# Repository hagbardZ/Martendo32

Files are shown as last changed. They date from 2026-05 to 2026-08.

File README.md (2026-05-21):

2026-04-28 11_06_20-_ Martendo32_Housingb_IPS - FreeCAD 1 1 1_C

assets/65467d34-9345-4316-92dd-8e191f508759" />
Kicad files for Martendo32.
An ESP32-P4 based Retro Game console

Martendo32Top

Martendo32BOT

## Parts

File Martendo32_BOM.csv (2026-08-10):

ID | Bezeichner | Footprint | Stückzahl | Bezeichnung | Anbieter und Referenz
1 | C1, C2, C3, C5, C7, C8 | 0603 | 6 | 10uF
2 | C4, C6, C9, C10, C11 | 0603 | 5 | 100nF
3 | C12 | 0805 | 1 | 10uF
4 | CN2 | CONN-SMD_2P-P1.25_D125F2W1-2W2P43 | 1 | ZX-MX1.25-2PWT
5 | CONBAT1, CONBAT2 | PinHeader_1x01_P2.54mm_Vertical | 2 | Conn_01x01
6 | CONBAT3, CONBAT4 | TestPoint_Pad_3.0x3.0mm | 2 | Conn_01x01
7 | D1 | SOD-123_L2.7-W1.6-LS3.7-RDaaa | 1 | 1N5819W
8 | D2 | SOD-123FL_L2.7-W1.8-LS3.8-RD | 1 | DSK24
9 | J1 | AUDIO-SMD_HOOYA_PJ-242a | 1 | AudioJack4_SwitchTR1
10 | J2 | PinSocket_1x03_P2.54mm_Vertical | 1 | Conn_01x03
11 | J3 | 687118183722 | 1 | Conn_01x18_Socket
12 | J4 | AMPHENOL_GSB1C41110SSHR | 1 | USB-C
13 | key_a1, key_down1, key_down2, key_left1, key_left2, key_right1, key_right2, key_select1, key_start1, key_up1, key_up2 | 430451031836 | 11 | TS-1187A-B-A-B
14 | key_a2 | DTSM-6 | 1 | TS-1187A-B-A-B
15 | L1 | IND-SMD_L2.5-W2.0_MHCH252012A | 1 | 4.7uH
16 | LCD1 | ILI9341-2.8a | 1 | Conn_01x18
17 | LED1 | LED0603-RD_GREEN | 1 | ~
18 | LED2 | LED0603-RD_RED | 1 | ~
19 | Q1 | SOT-23-3_L2.9-W1.6-P1.90-LS2.8-BRaaa | 1 | NPN
20 | Q2 | SOT-23-3_L2.9-W1.6-P1.90-LS2.8-BR | 1 | AO3401A
21 | R1, R13 | 0603 | 2 | 10K
22 | R2, R22, R23 | 0603 | 3 | 100K
23 | R3 | 0603 | 1 | 2K
24 | R4, R6, R7 | 0603 | 3 | 5K1
25 | R5, R14, R25 | 0603 | 3 | 1K
26 | R8 | 0603 | 1 | 240R
27 | R9, R10, R11, R12 | 0603 | 4 | 10R
28 | R15, R16, R17, R18, R19 | 0603 | 5 | 10kΩ
29 | R20 | 0603 | 1 | 220K
30 | R21 | 0603 | 1 | 680K
31 | R24 | 0603 | 1 | 10K
32 | R26 | R_0603_1608Metric_Pad0.98x0.95mm_HandSolder | 1 | 10K
33 | R111 | 0603 | 1 | 0R
34 | REF** | BATT_CONN_SMT_292173 | 1 | BATT_CONN_SMT_292173
35 | RP1, RP2 | Adafruit_2765 | 2 | Adafruit_2765
36 | SD1 | TF-SMD_TF-01A | 1 | ~
37 | SPK1, SPK11 | TestPoint_Pad_D2.5mm | 2 | Conn_01x01
38 | SW1 | SW-SMD_MSK12C02-HB | 1 | SK-3296S-01-L3
39 | SW_BOOT1, SW_RST1 | SW-SMD_L3.9-W3.0-P4.45 | 2 | 3*4 龟仔/微动/轻触开关
40 | TP1, TP2, TP3, TP4, TP5, TP6, TP7, TP8, TP9, TP10, TP11, TP12, TP13, TP14, TP15, TP16, TP17, TP18, TP19, TP20, TP21, TP22, TP23 | TestPoint_Pad_D1.0mm | 23 | TestPoint
41 | U1 | COMM-SMD_L25.0-W20.0-P1.00_WT0132P4-A1 | 1 | ~
42 | U3 | ESOP-8_L4.9-W3.9-P1.27-LS6.0-BL-EP | 1 | TP4056
43 | U4 | ESOP-8_L4.9-W3.9-P1.27-LS6.0-BL-EP | 1 | NS4168
44 | U5 | SOT-23-5_L3.0-W1.7-P0.95-LS2.8-BR | 1 | TPS61040DBV
45 | U6 | SOT-23-5_L2.9-W1.6-P0.95-LS2.8-BR | 1 | AP2112K-3.3
46 | VR1 | RK10J11E002Y | 1 | RK10J11E002Y
47 | X22, X23 |  | 2

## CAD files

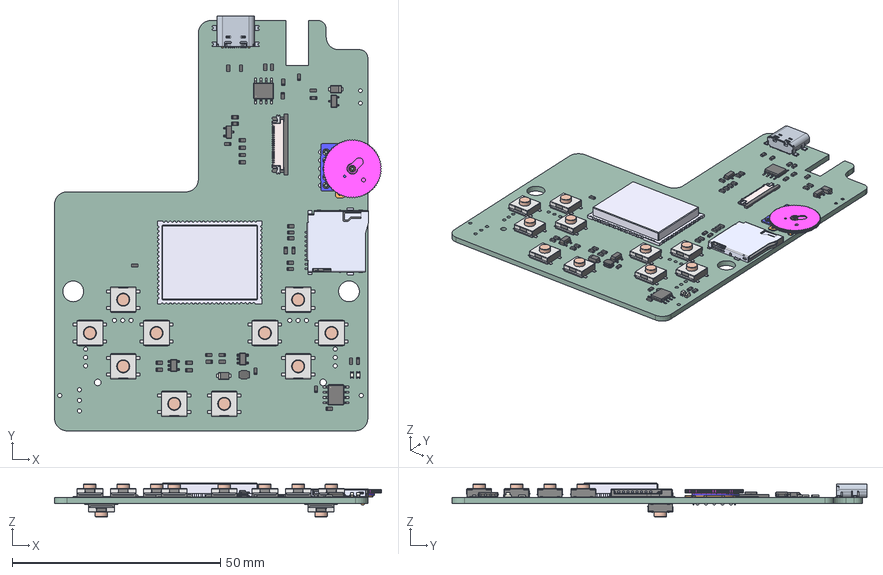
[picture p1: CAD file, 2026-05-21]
Martendo32_PCBA_V2.2.step
78.5 x 99.6 x 8.08 mm
R_0603_1608Metric x 37
base x 12
top cover x 12
6081697a-9268-11ed-8af4-a0cec80452fd_part x 2
60816e3e-9268-11ed-8af4-a0cec80452fd_part x 2
6081710e-9268-11ed-8af4-a0cec80452fd_part x 2
6081737a-9268-11ed-8af4-a0cec80452fd_part x 2
SOT-23-3 x 2
68x118183x22
68X1XX183X22_Pin_Bottom x 18
68x118183x22_Actuator
68X1XX183X22_Solder_Pad
68X1xx183x22_Solder_Pad2
TF-01A_TF-01A
HTSOP-8-1EP_3.9x4.9mm_P1.27mm_EP2.4x3.2mm x 2
_16P_7_35_3D_
SOT-23-5 x 2
LED_0603_1608Metric_Castellated x 2
RK10J1_E
L_Wurth_WE-LQSH-2010
L_Wurth_WE-LQSH-2512
Martendo32_PCB

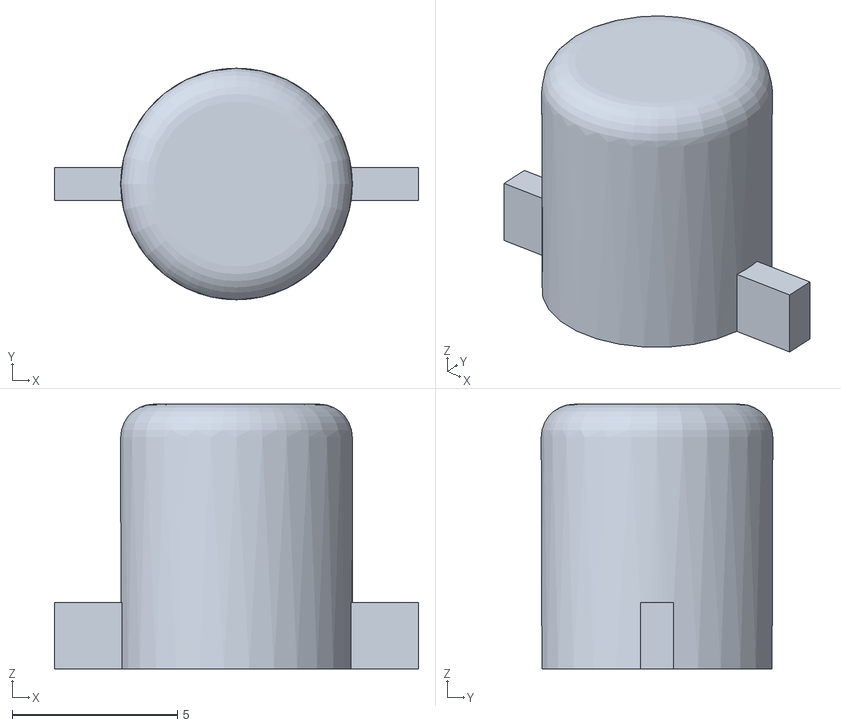
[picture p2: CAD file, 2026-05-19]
Martendo32_H-Button.stl
11.0 x 7.00 x 8.00

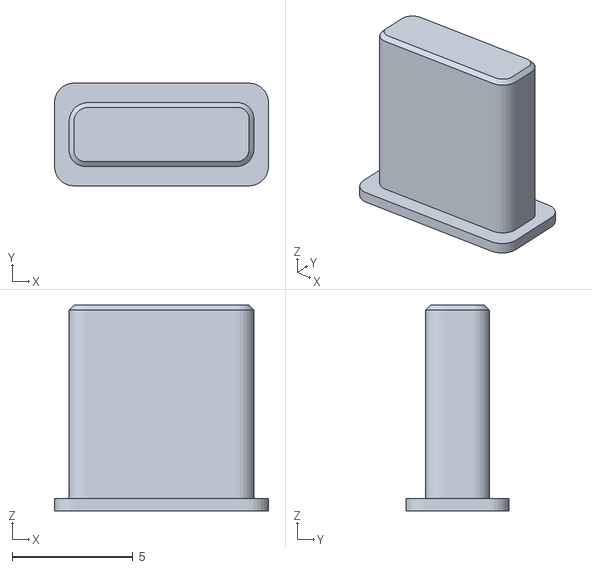
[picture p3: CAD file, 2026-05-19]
Martendo32_H-ButtonUnten.stl
8.85 x 4.25 x 8.50

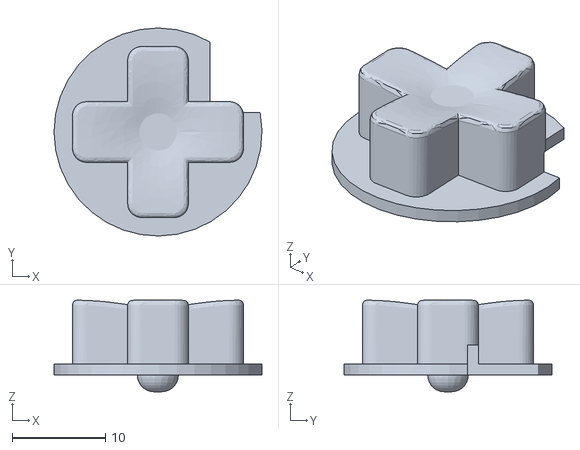
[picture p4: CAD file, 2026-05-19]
Martendo32_H_Steuerkreuz.stl
22.2 x 22.2 x 9.80

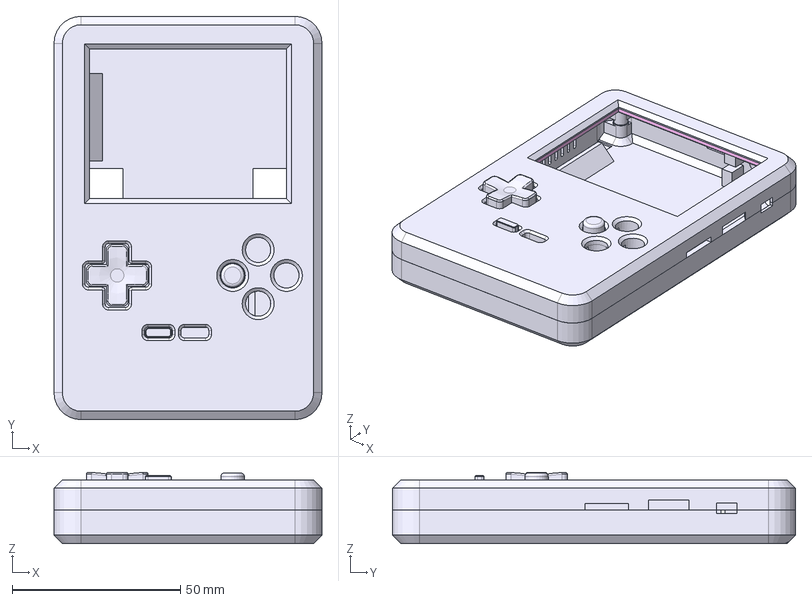
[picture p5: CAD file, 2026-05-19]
Martendo32_H.step
79.8 x 120.0 x 21.2 mm
Steuerkreuz002
Button001
ButtonUnten
GUT002_mitVertiefungen
IPS-FRAME_extrude
GOT002_M2Inserts
Insert_M2 v2
Insert_M2 v001
Insert_M2 v002
Insert_M2 v003
Insert_M2 v004
Insert_M2 v005

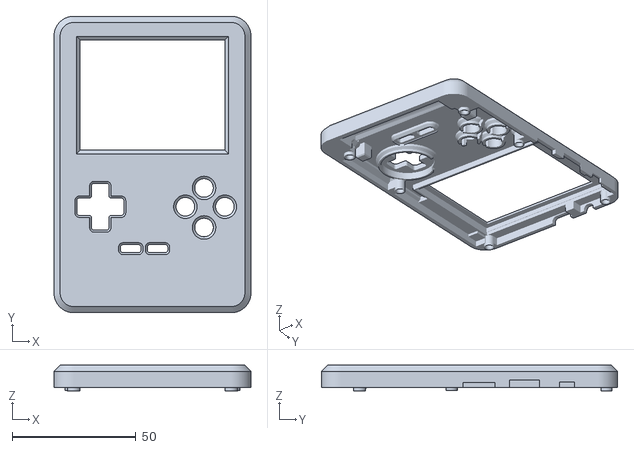
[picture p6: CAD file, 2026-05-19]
Martendo32_H_GOT.stl
79.8 x 120.0 x 10.4

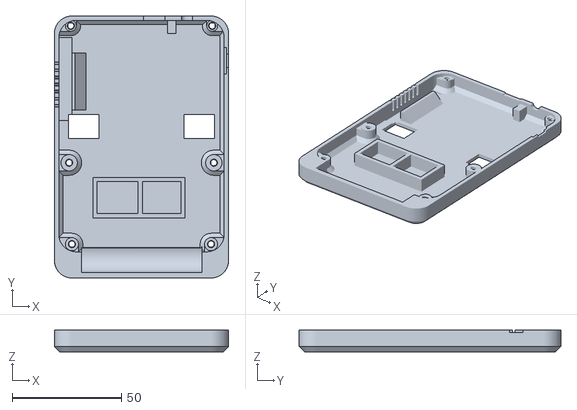
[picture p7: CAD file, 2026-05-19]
Martendo32_H_GUT.stl
79.8 x 120.0 x 10.0

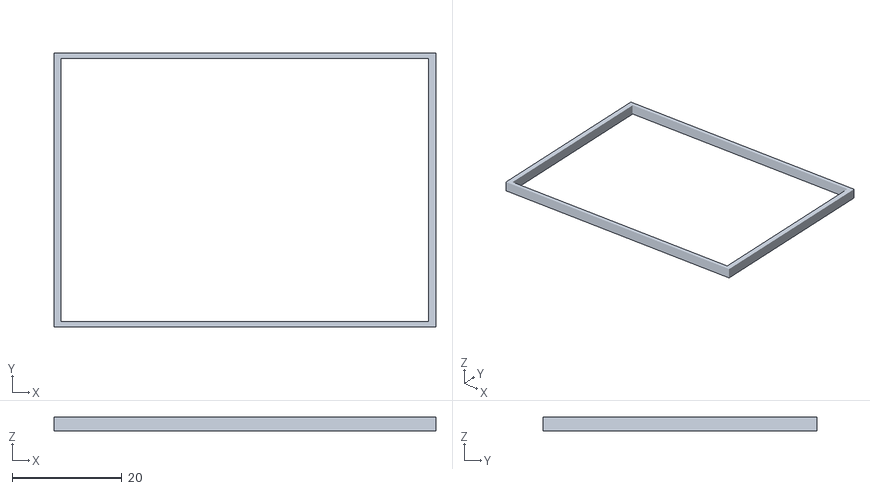
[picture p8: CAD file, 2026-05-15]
Martendo32_H_IPS-FRAME.stl
69.7 x 49.9 x 2.50

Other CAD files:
Martendo32_Housingh-IPS.FCStd

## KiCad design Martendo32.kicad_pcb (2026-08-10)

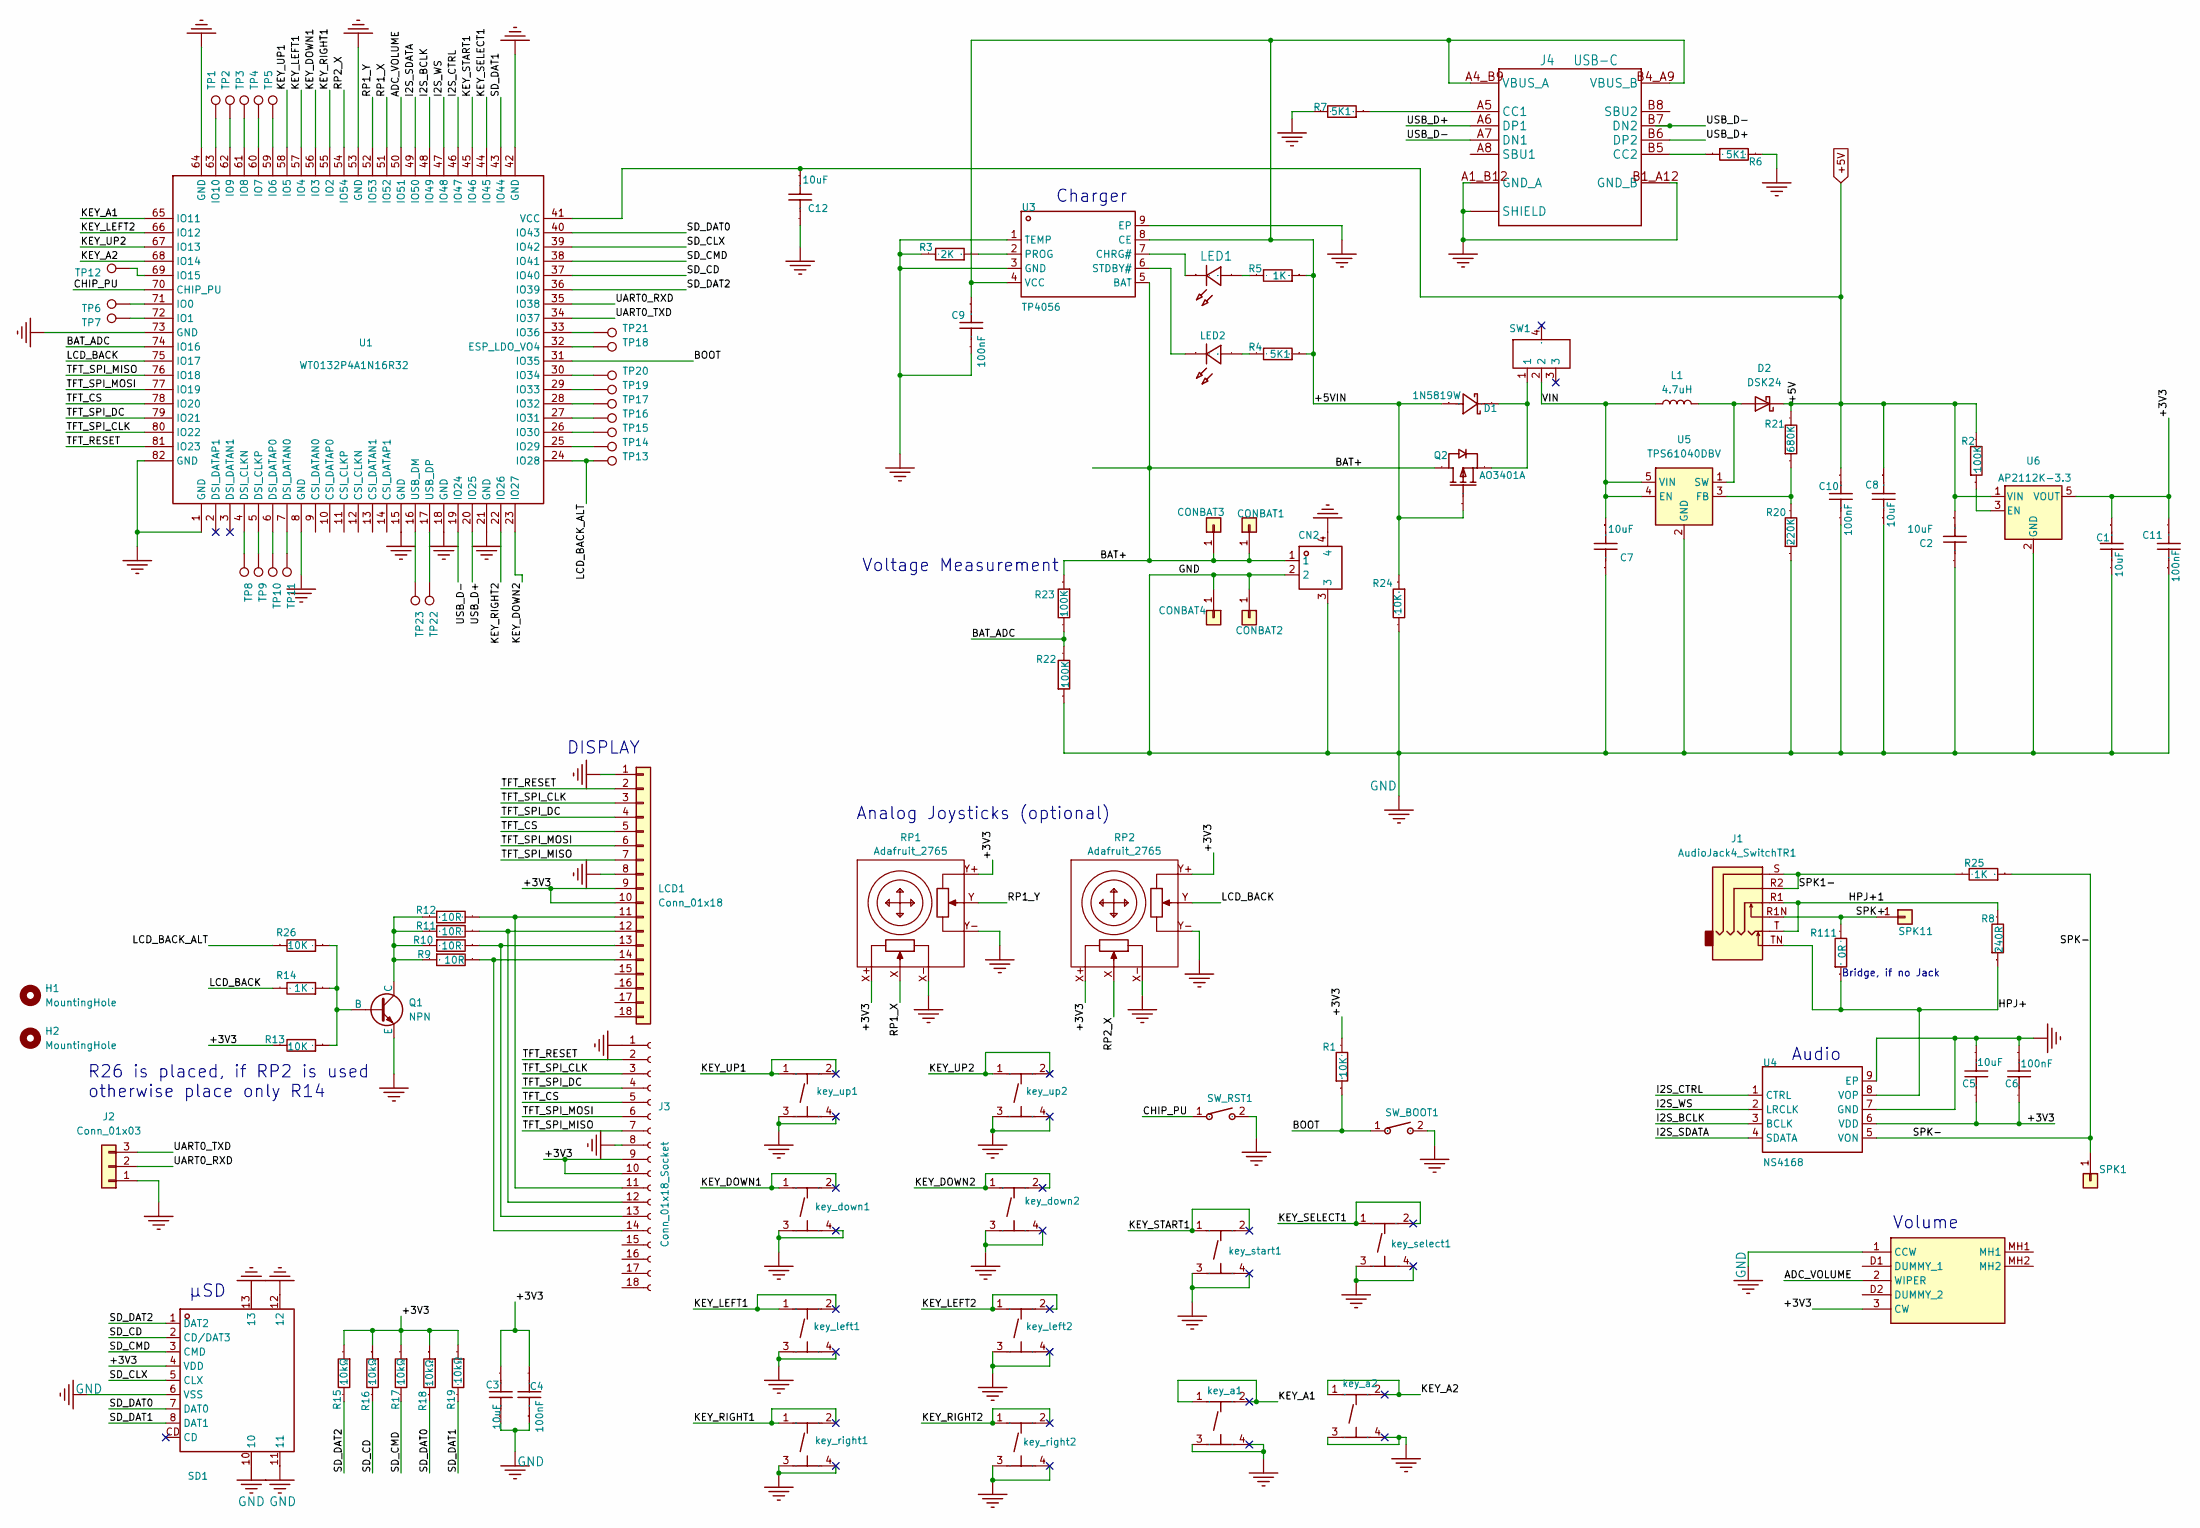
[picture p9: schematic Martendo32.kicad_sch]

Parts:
C1, C2, C5: 10uF; 0603; Manufacturer Part CL10A106MA8NRNC; LCSC Part Name 10uF ±20% 25V
C3: 10uF; 0603; Manufacturer Part CGA0603X5R106K100JT; LCSC Part Name 10uF ±10% 10V
C4: 100nF; 0603; Manufacturer Part CGA0603X7R104K500JT; LCSC Part Name 100nF ±10% 50V
C6, C11: 100nF; 0603; Manufacturer Part CL10A106MA8NRNC; LCSC Part Name 10uF ±20% 25V
C7, C8: 10uF; 0603
C9, C10: 100nF; 0603
C12: 10uF; 0805
CN2: ZX-MX1.25-2PWT; CONN-SMD_2P-P1.25_D125F2W1-2W2P43; Manufacturer Part ZX-MX1.25-2PWT; LCSC Part Name 1x2P 间距:1.25mm 卧贴
CONBAT1, CONBAT2: Conn_01x01; PinHeader_1x01_P2.54mm_Vertical
CONBAT3, CONBAT4: Conn_01x01; TestPoint_Pad_3.0x3.0mm
D1: 1N5819W; SOD-123_L2.7-W1.6-LS3.7-RDaaa; Manufacturer Part 1N5819W; LCSC Part Name 电压:40V 电流:350mA
D2: DSK24; SOD-123FL_L2.7-W1.8-LS3.8-RD
H1, H2: MountingHole; MountingHole_5mm
J1: AudioJack4_SwitchTR1; AUDIO-SMD_HOOYA_PJ-242a
J2: Conn_01x03; PinSocket_1x03_P2.54mm_Vertical
J3: Conn_01x18_Socket; 687118183722
J4: USB-C; AMPHENOL_GSB1C41110SSHR
L1: 4.7uH; IND-SMD_L2.5-W2.0_MHCH252012A
LCD1: Conn_01x18; ILI9341-2.8a
LED1: LED0603-RD_GREEN
LED2: LED0603-RD_RED
Q1: NPN; SOT-23-3_L2.9-W1.6-P1.90-LS2.8-BRaaa
Q2: AO3401A; SOT-23-3_L2.9-W1.6-P1.90-LS2.8-BR; Manufacturer Part AO3401A; LCSC Part Name P沟道 耐压:30V 电流:4A
R1, R13, R24: 10K; 0603
R2, R22, R23: 100K; 0603
R3: 2K; 0603
R4, R6, R7: 5K1; 0603
R5, R14, R25: 1K; 0603
R8: 240R; 0603
R9, R10, R11, R12: 10R; 0603
R15, R16, R17, R18, R19: 10kΩ; 0603; Voltage-Supply(Max) 75V; Manufacturer Part 0603WAF1002T5E; LCSC Part Name 厚膜电阻 10kΩ ±1% 100mW
R20: 220K; 0603
R21: 680K; 0603
R26: 10K; R_0603_1608Metric_Pad0.98x0.95mm_HandSolder
R111: 0R; 0603
RP1, RP2: Adafruit_2765; PartNumber 2765
SD1: TF-SMD_TF-01A; Manufacturer Part TF PUSH; LCSC Part Name 自弹式 MicroSD卡(TF卡) 卡座
SPK1, SPK11: Conn_01x01; TestPoint_Pad_D2.5mm
SW1: SK-3296S-01-L3; SW-SMD_MSK12C02-HB; Manufacturer Part SK-3296S-01-L3; LCSC Part Name 柄长2.5mm 卧贴双档 滑动开关
SW_BOOT1: 3*4 龟仔/微动/轻触开关; SW-SMD_L3.9-W3.0-P4.45; Manufacturer Part 3*4 龟仔/微动/轻触开关; LCSC Part Name 3*4 龟仔/微动/轻触开关
SW_RST1: 3*4 龟仔/微动/轻触开关; SW-SMD_L3.9-W3.0-P4.45; Manufacturer Part 3*4 龟仔/微动/轻触开关; LCSC Part Name 3*4 龟仔/微动/轻触开关
TP1, TP2, TP3, TP4, TP5, TP6, TP7, TP8, TP9, TP10, TP11, TP12, TP13, TP14, TP15, TP16, TP17, TP18, TP19, TP20, TP21, TP22, TP23: TestPoint; TestPoint_Pad_D1.0mm
U1: WT0132P4A1N16R32; COMM-SMD_L25.0-W20.0-P1.00_WT0132P4-A1
U3: TP4056; ESOP-8_L4.9-W3.9-P1.27-LS6.0-BL-EP; Manufacturer Part TP4056; LCSC Part Name TP4056
U4: NS4168; ESOP-8_L4.9-W3.9-P1.27-LS6.0-BL-EP; Manufacturer Part NS4168; LCSC Part Name NS4168
U5: TPS61040DBV; SOT-23-5_L3.0-W1.7-P0.95-LS2.8-BR
U6: AP2112K-3.3; SOT-23-5_L2.9-W1.6-P0.95-LS2.8-BR
VR1: RK10J11E002Y; Manufacturer_Part_Number RK10J11E002Y; Mouser Part Number 688-RK10J11E002Y
key_a1: TS-1187A-B-A-B; 430451031836; Manufacturer Part TS-1187A-B-A-B; LCSC Part Name 5.1*5.1*1.5mm 立贴 轻触开关
key_a2: TS-1187A-B-A-B; DTSM-6; Manufacturer Part TS-1187A-B-A-B; LCSC Part Name 5.1*5.1*1.5mm 立贴 轻触开关
key_down1, key_down2: TS-1187A-B-A-B; 430451031836; Manufacturer Part TS-1187A-B-A-B; LCSC Part Name 5.1*5.1*1.5mm 立贴 轻触开关
key_left1, key_left2: TS-1187A-B-A-B; 430451031836; Manufacturer Part TS-1187A-B-A-B; LCSC Part Name 5.1*5.1*1.5mm 立贴 轻触开关
key_right1, key_right2: TS-1187A-B-A-B; 430451031836; Manufacturer Part TS-1187A-B-A-B; LCSC Part Name 5.1*5.1*1.5mm 立贴 轻触开关
key_select1: TS-1187A-B-A-B; 430451031836; Manufacturer Part TS-1187A-B-A-B; LCSC Part Name 5.1*5.1*1.5mm 立贴 轻触开关
key_start1: TS-1187A-B-A-B; 430451031836; Manufacturer Part TS-1187A-B-A-B; LCSC Part Name 5.1*5.1*1.5mm 立贴 轻触开关
key_up1, key_up2: TS-1187A-B-A-B; 430451031836; Manufacturer Part TS-1187A-B-A-B; LCSC Part Name 5.1*5.1*1.5mm 立贴 轻触开关

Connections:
+5V: C2.1, C8.1, C10.1, C12.1, D2.1 (K), R2.2, R21.2, U1.41 (VCC), U6.1 (VIN)
/+3V3: C1.1, C3.2, C4.2, C5.2, C6.2, C11.2, J3.9, J3.10, LCD1.9, LCD1.10, R1.2, R13.2, R15.1, R16.1, R17.1, R18.1, R19.1, RP1.X+, RP1.Y+, RP2.X+, RP2.Y+, SD1.4 (VDD), U4.6 (VDD), U6.5 (VOUT), VR1.3 (CW)
/+5VIN: C9.1, D1.1 (A), J4.A4_B9 (VBUS_A), J4.B4_A9 (VBUS_B), Q2.1 (G), R4.1, R5.1, R24.1, U3.4 (VCC), U3.8 (CE)
/ADC_VOLUME: U1.50 (IO51), VR1.2 (WIPER)
/BAT+: CN2.1, CONBAT1.1 (Pin_1_1), CONBAT3.1 (Pin_1_1), Q2.3 (D), R23.1, U3.5 (BAT)
/BAT_ADC: R22.2, R23.2, U1.74 (IO16)
/BOOT: R1.1, SW_BOOT1.1, U1.31 (IO35)
/CHIP_PU: SW_RST1.1, U1.70 (CHIP_PU)
/HPJ+: J1.TN, R8.1, R111.1, U4.8 (VOP)
/HPJ+1: J1.R1, J1.T, R8.2
/I2S_BCLK: U1.48 (IO49), U4.3 (BCLK)
/I2S_CTRL: U1.46 (IO47), U4.1 (CTRL)
/I2S_SDATA: U1.49 (IO50), U4.4 (SDATA)
/I2S_WS: U1.47 (IO48), U4.2 (LRCLK)
/KEY_A1: U1.65 (IO11), key_a1.1 (A), key_a1.2 (B)
/KEY_A2: U1.68 (IO14), key_a2.1 (A), key_a2.2 (B)
/KEY_DOWN1: U1.56 (IO3), key_down1.1 (A), key_down1.2 (B)
/KEY_DOWN2: U1.23 (IO27), key_down2.1 (A), key_down2.2 (B)
/KEY_LEFT1: U1.57 (IO4), key_left1.1 (A), key_left1.2 (B)
/KEY_LEFT2: U1.66 (IO12), key_left2.1 (A), key_left2.2 (B)
/KEY_RIGHT1: U1.55 (IO2), key_right1.1 (A), key_right1.2 (B)
/KEY_RIGHT2: U1.22 (IO26), key_right2.1 (A), key_right2.2 (B)
/KEY_SELECT1: U1.44 (IO45), key_select1.1 (A), key_select1.2 (B)
/KEY_START1: U1.45 (IO46), key_start1.1 (A), key_start1.2 (B)
/KEY_UP1: U1.58 (IO5), key_up1.1 (A), key_up1.2 (B)
/KEY_UP2: U1.67 (IO13), key_up2.1 (A), key_up2.2 (B)
/LCD_BACK: R14.2, RP2.Y, U1.75 (IO17)
/LCD_BACK_ALT: R26.2, TP13.1 (1_1), U1.24 (IO28)
/RP1_X: RP1.X, U1.51 (IO52)
/RP1_Y: RP1.Y, U1.52 (IO53)
/RP2_X: RP2.X, U1.54 (IO54)
/SD_CD: R16.2, SD1.2 (CD/DAT3), U1.37 (IO40)
/SD_CLX: SD1.5 (CLX), U1.39 (IO42)
/SD_CMD: R17.2, SD1.3 (CMD), U1.38 (IO41)
/SD_DAT0: R18.2, SD1.7 (DAT0), U1.40 (IO43)
/SD_DAT1: R19.2, SD1.8 (DAT1), U1.43 (IO44)
/SD_DAT2: R15.2, SD1.1 (DAT2), U1.36 (IO39)
/SPK1-: J1.R2, J1.S, R25.2
/SPK+: J1.R1N, R111.2, SPK11.1 (Pin_1_1)
/SPK-: R25.1, SPK1.1 (Pin_1_1), U4.5 (VON)
/TFT_CS: J3.5, LCD1.5, U1.78 (IO20)
/TFT_RESET: J3.2, LCD1.2, U1.81 (IO23)
/TFT_SPI_CLK: J3.3, LCD1.3, U1.80 (IO22)
/TFT_SPI_DC: J3.4, LCD1.4, U1.79 (IO21)
/TFT_SPI_MISO: J3.7, LCD1.7, U1.76 (IO18)
/TFT_SPI_MOSI: J3.6, LCD1.6, U1.77 (IO19)
/UART0_RXD: J2.2, U1.35 (IO38)
/UART0_TXD: J2.3, U1.34 (IO37)
/USB_D+: J4.A6 (DP1), J4.B6 (DP2), U1.20 (IO25)
/USB_D-: J4.A7 (DN1), J4.B7 (DN2), U1.19 (IO24)
/VIN: C7.1, L1.1, SW1.2, U5.4 (EN), U5.5 (VIN)
GND: C1.2, C2.2, C3.1, C4.1, C5.1, C6.1, C7.2, C8.2, C9.2, C10.2, C11.1, C12.2, CN2.2, CN2.3, CN2.4, CONBAT2.1 (Pin_1_1), CONBAT4.1 (Pin_1_1), J2.1, J3.1, J3.8, J3.Z1, J3.Z2, J4.A1_B12 (GND_A), J4.B1_A12 (GND_B), J4.SH1 (SHIELD), J4.SH2 (SHIELD), J4.SH3 (SHIELD), J4.SH4 (SHIELD), LCD1.1, LCD1.8, Q1.3 (E), R3.2, R6.2, R7.2, R20.1, R22.1, R24.2, RP1.X-, RP1.Y-, RP2.X-, RP2.Y-, SD1.6 (VSS), SD1.10, SD1.11, SD1.12, SD1.13, SW_BOOT1.2, SW_RST1.2, U1.1 (GND), U1.8 (GND), U1.15 (GND), U1.18 (GND), U1.21 (GND), U1.42 (GND), U1.53 (GND), U1.64 (GND), U1.73 (GND), U1.82 (GND), U3.1 (TEMP), U3.3 (GND), U3.9 (EP), U4.7 (GND), U4.9 (EP), U5.2 (GND), U6.2 (GND), VR1.1 (CCW), key_a1.3 (C), key_a1.4 (D), key_a2.3 (C), key_a2.4 (D), key_down1.3 (C), key_down1.4 (D), key_down2.3 (C), key_down2.4 (D), key_left1.3 (C), key_left1.4 (D), key_left2.3 (C), key_left2.4 (D), key_right1.3 (C), key_right1.4 (D), key_right2.3 (C), key_right2.4 (D), key_select1.3 (C), key_select1.4 (D), key_start1.3 (C), key_start1.4 (D), key_up1.3 (C), key_up1.4 (D), key_up2.3 (C), key_up2.4 (D); also elsewhere on the board
unnamed: D1.2 (C), Q2.2 (S), SW1.1
unnamed: D2.2 (A), L1.2, U5.1 (SW)
unnamed: J3.11, LCD1.11, R12.2
unnamed: J3.12, LCD1.12, R11.2
unnamed: J3.13, LCD1.13, R10.2
unnamed: J3.14, LCD1.14, R9.2
unnamed: J4.A5 (CC1), R7.1
unnamed: J4.B5 (CC2), R6.1
unnamed: LED1.2 (A), R5.2
unnamed: LED1.1 (C), U3.7 (CHRG#)
unnamed: LED2.2 (A), R4.2
unnamed: LED2.1 (C), U3.6 (STDBY#)
unnamed: Q1.2 (B), R13.1, R14.1, R26.1
unnamed: Q1.1 (C), R9.1, R10.1, R11.1, R12.1
unnamed: TP8.1 (1_1), U1.4 (DSI_CLKN)
unnamed: TP9.1 (1_1), U1.5 (DSI_CLKP)
unnamed: TP11.1 (1_1), U1.7 (DSI_DATAN0)
unnamed: TP10.1 (1_1), U1.6 (DSI_DATAP0)
unnamed: TP18.1 (1_1), U1.32 (ESP_LDO_VO4)
unnamed: TP6.1 (1_1), U1.71 (IO0)
unnamed: TP7.1 (1_1), U1.72 (IO1)
unnamed: TP5.1 (1_1), U1.59 (IO6)
unnamed: TP4.1 (1_1), U1.60 (IO7)
unnamed: TP3.1 (1_1), U1.61 (IO8)
unnamed: TP2.1 (1_1), U1.62 (IO9)
unnamed: TP1.1 (1_1), U1.63 (IO10)
unnamed: TP12.1 (1_1), U1.69 (IO15)
unnamed: TP14.1 (1_1), U1.25 (IO29)
unnamed: TP15.1 (1_1), U1.26 (IO30)
unnamed: TP16.1 (1_1), U1.27 (IO31)
unnamed: TP17.1 (1_1), U1.28 (IO32)
unnamed: TP19.1 (1_1), U1.29 (IO33)
unnamed: TP20.1 (1_1), U1.30 (IO34)
unnamed: TP21.1 (1_1), U1.33 (IO36)
unnamed: TP23.1 (1_1), U1.16 (USB_DM)
unnamed: TP22.1 (1_1), U1.17 (USB_DP)
unnamed: R3.1, U3.2 (PROG)
unnamed: R20.2, R21.1, U5.3 (FB)
unnamed: R2.1, U6.3 (EN)

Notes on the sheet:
R26 is placed, if RP2 is used otherwise place only R14
Analog Joysticks (optional)
µSD
DISPLAY
Audio
Volume
Charger
Voltage Measurement
Bridge, if no Jack

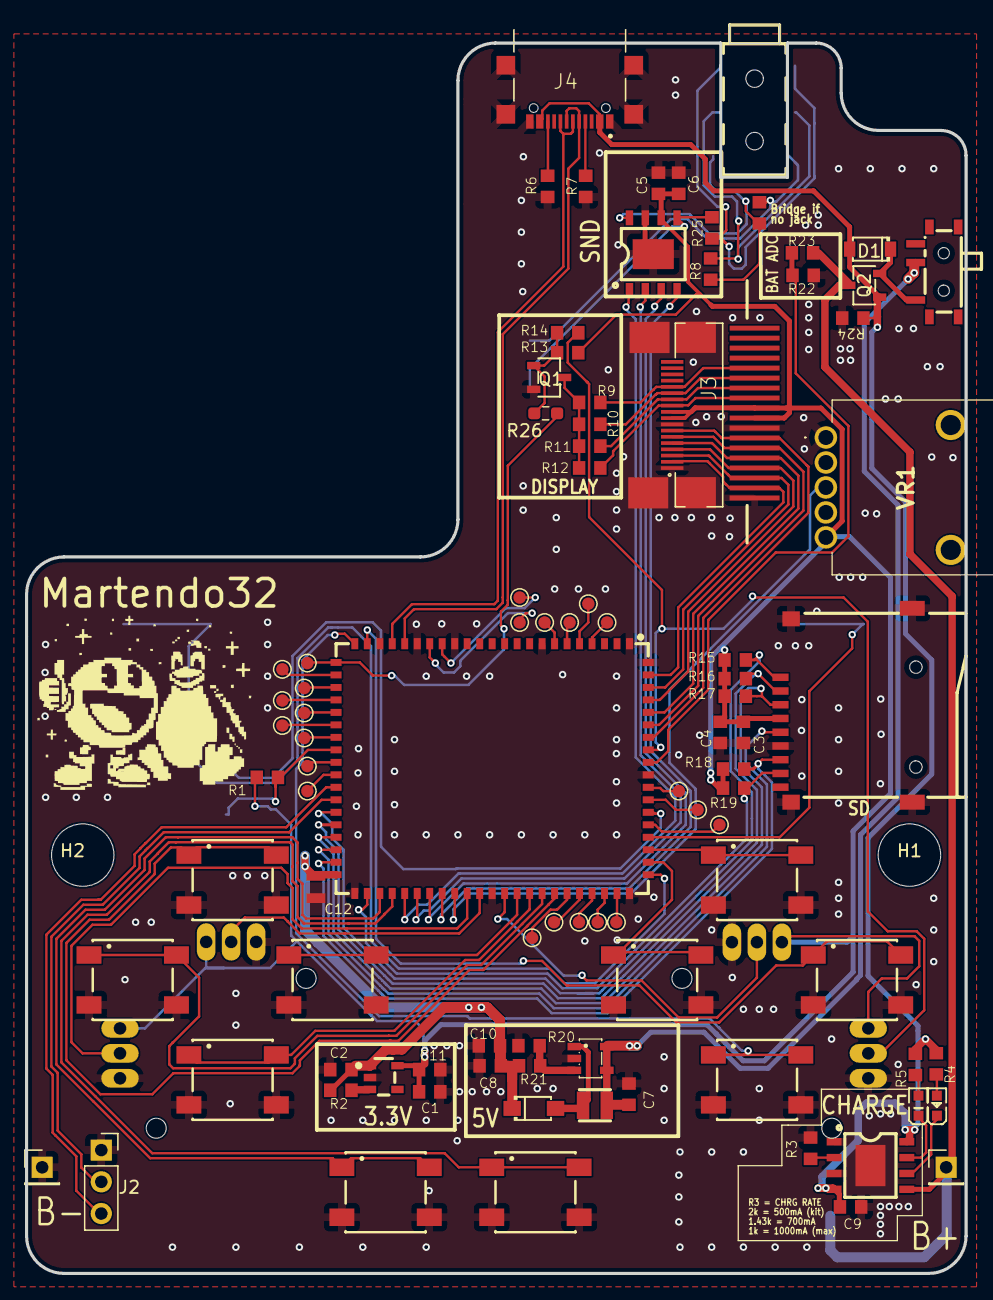
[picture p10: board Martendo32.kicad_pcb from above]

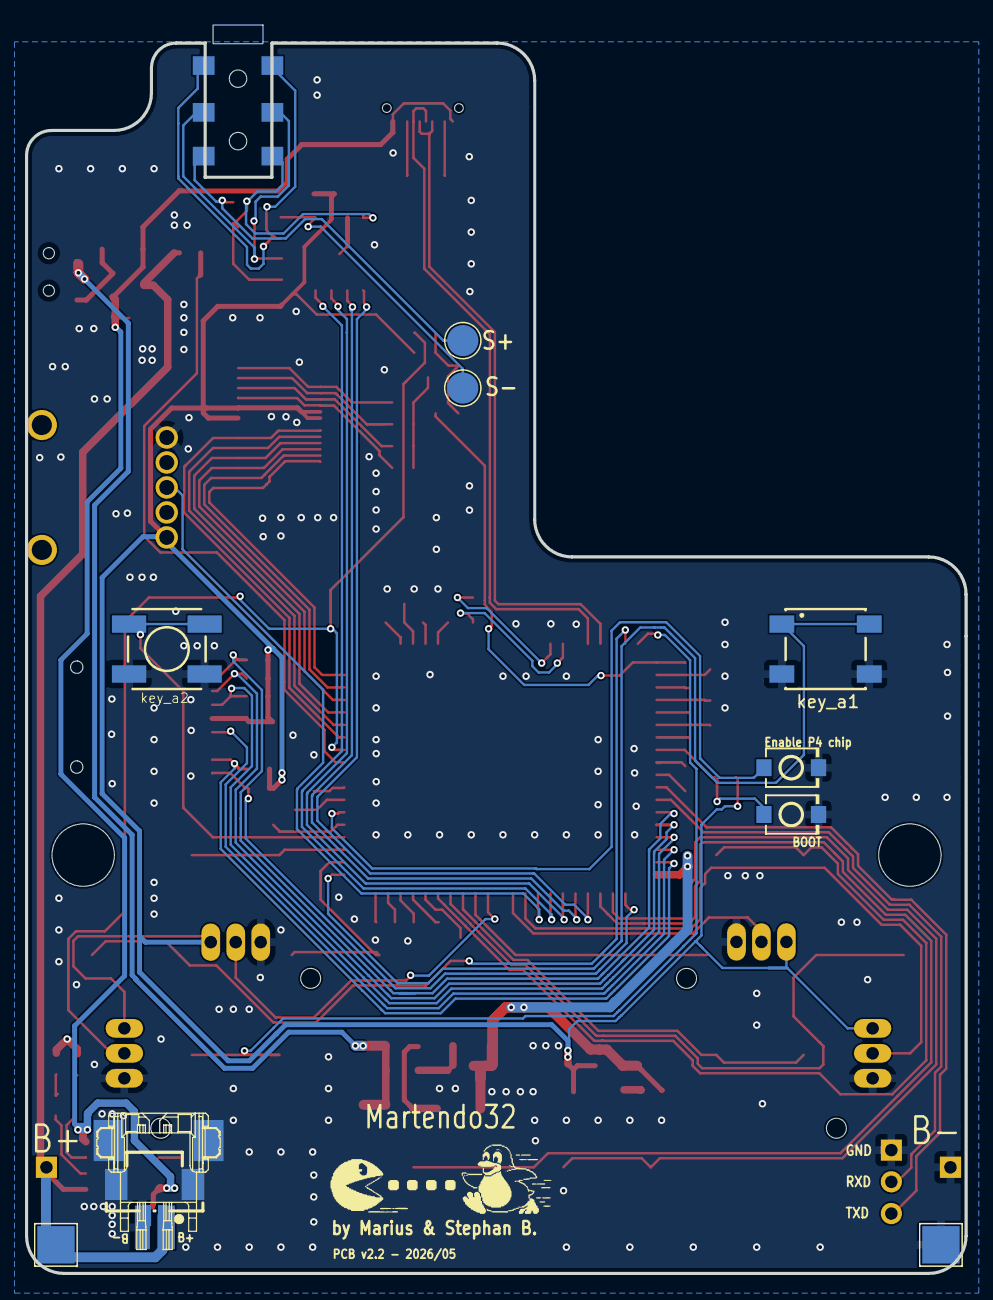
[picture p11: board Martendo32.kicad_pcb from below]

Board: 2 copper layers, 75.2 x 100.0 mm, 109 parts (9 on the bottom side), 91 nets.

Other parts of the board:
X22, X23: (no value)

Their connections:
GND: X22.Z2, X23.Z1; also elsewhere on the board

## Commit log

2026-01-22 Add files via upload
    added Analog Joysticks RP1/RP1
    [Martendo32.kicad_pcb, Martendo32.kicad_sch]
2026-01-22 Add files via upload
    improved Silkscreen
    [Martendo32.kicad_pcb, Martendo32.kicad_sch]
2026-04-28 Add files via upload
    Upper Housing with frame for IPS Display (IPS Display is smaller than TFT)
    [Martendo32_Housingb_IPS.FCStd]
2026-04-28 Update README.md
    added picture from housing
2026-04-28 Add files via upload
    updated chamfers
    [Martendo32_Housingb_IPS.FCStd]
2026-04-28 Add files via upload
    added stl parts
    [Martendo32_Housingb_GOT_with_IPS_Frame.stl, Martendo32_Housingb_GOT_without_IPS_Frame.stl, Martendo32_Housingb_IPS-Body002IPS_FRAME.stl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]
2026-04-29 Add files via upload
    changed IPS frame
    [Martendo32_Housingb_IPS.FCStd, Martendo32_IPS_FrameOnly.stl]
2026-05-28 added value to U1
    [Martendo32.kicad_sch]
2026-08-10 minor PCB changes
    [Martendo32.kicad_pcb]
2026-08-10 added BOM
    [Martendo32_BOM.csv]
